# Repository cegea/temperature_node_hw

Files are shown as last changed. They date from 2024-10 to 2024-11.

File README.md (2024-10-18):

# Temperature node
PCB design for a temperature sensor based on SHT and ESP32.

#  Requirement Specifications

- Battery Operated: The node should operate on a battery with a lifespan of over a month.
- WiFi Connection: Supports 2.4 GHz WiFi to connect to a home network.
- MQTT Protocol: Publishes temperature and humidity data to an MQTT broker.
- Compact Design: Designed for easy placement in various locations around the home.
- Temperature and Humidity Reporting: Uses an SHT series sensor for accurate measurements.

# Functional Requirements Specification
## Electrical

- Battery Life: Should last more than a month on a single charge.
- Power Consumption: Optimized deep-sleep mode for low power consumption between readings.
- Input Voltage: 3.3V for ESP32 and 3V to 5V compatible for SHT sensors.
- Charging: Option for USB-C charging or solar panel for extended battery life.
- Voltage Regulation: Include a voltage regulator to ensure stable power delivery to ESP32 and the sensor.

## Mechanical

- Enclosure: IP65-rated enclosure for dust and water resistance if placed in areas prone to moisture.
- Size: Compact size, around 5cm x 5cm x 3cm, to fit easily on shelves or mounted on walls.
- Mounting (Optional): Option for wall mounting with screw holes or adhesive backing.
- Internal Antenna: PCB antenna for better WiFi range within the home.
- Access Ports: A small access port for USB charging and maintenance.

## Functional

- Data Reporting Interval: Configurable reporting interval (e.g., every 5 minutes, 10 minutes) to balance battery life and data frequency.
- Low Battery Alert: Sends an MQTT message when the battery level falls below a certain threshold.
- Temperature Range: Measures temperature from -20°C to +60°C.
- Humidity Range: Measures humidity from 0% to 100% relative humidity.
- OTA Updates: Supports Over-the-Air (OTA) firmware updates to improve functionality without physical access.
- Reconnection Logic: Automatically attempts to reconnect to WiFi and MQTT broker in case of network loss.
- Local Data Storage: Stores data temporarily in case of WiFi disconnection and uploads when the connection is restored.

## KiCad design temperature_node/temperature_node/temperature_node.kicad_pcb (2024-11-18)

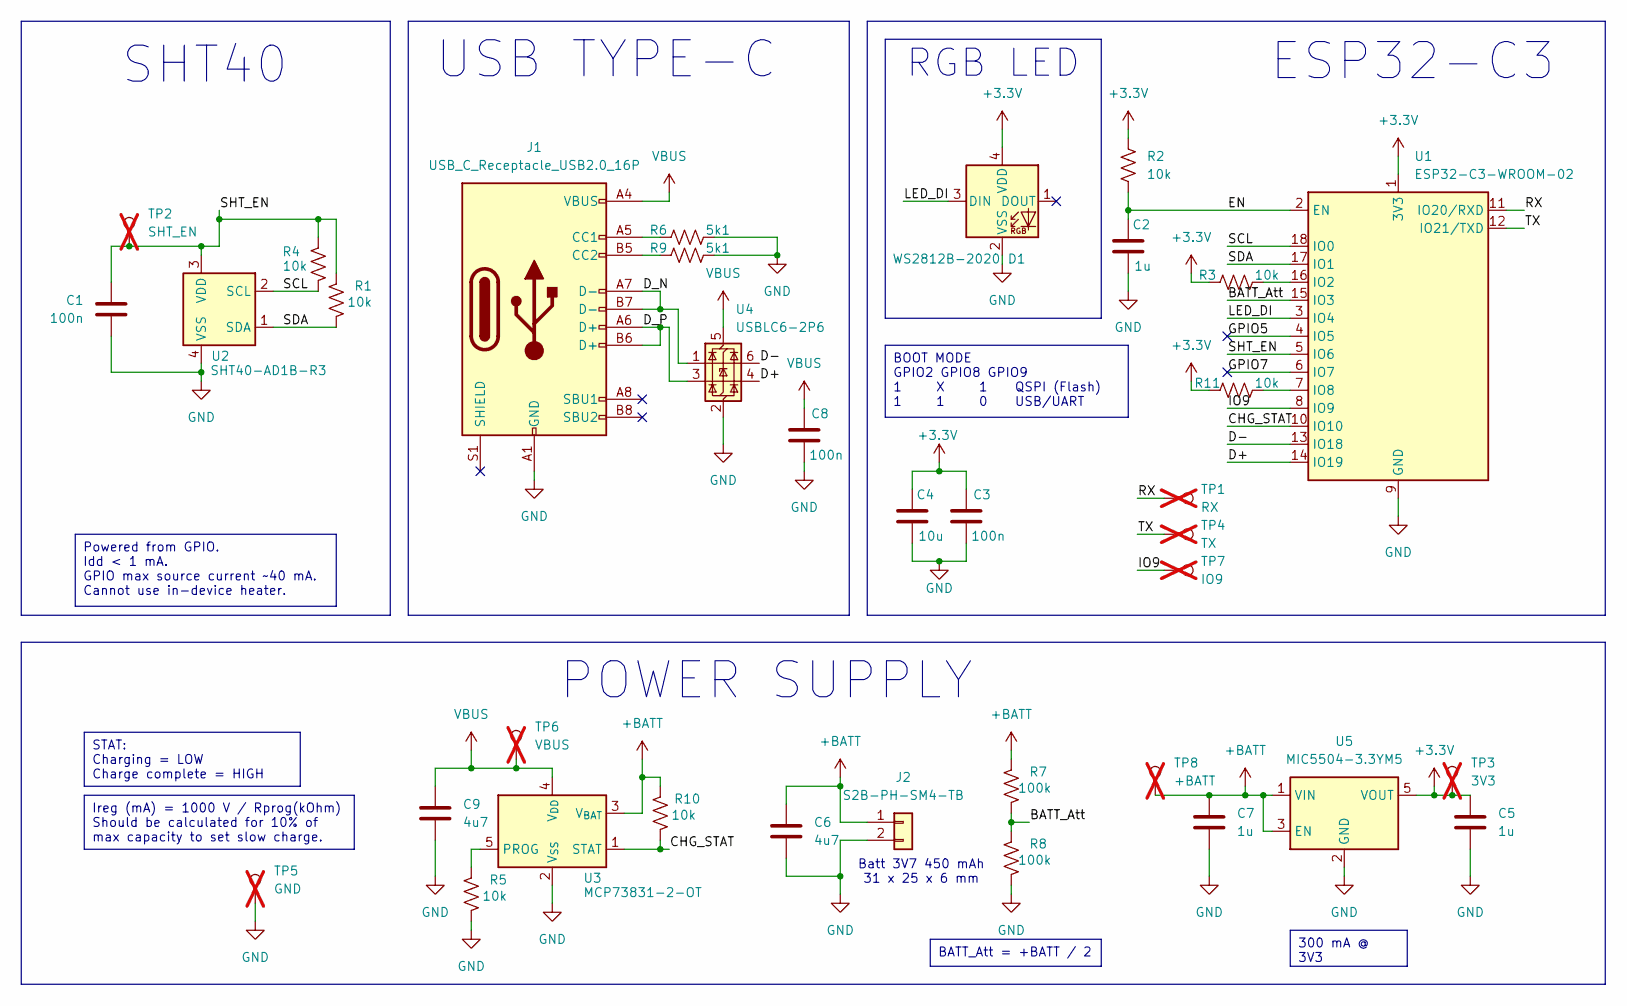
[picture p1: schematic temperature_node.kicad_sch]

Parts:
C1, C3, C8: 100n; C_0402_1005Metric; LCSC PN C60474
C2, C5, C7: 1u; C_0402_1005Metric; LCSC PN C60474
C4: 10u; C_0805_2012Metric; LCSC PN C17024
C6, C9: 4u7; C_0603_1608Metric; LCSC PN C913474
D1: WS2812B-2020; LED_WS2812B-2020_PLCC4_2.0x2.0mm; LCSC PN C965555
J1: USB_C_Receptacle_USB2.0_16P; USB_C_Receptacle_GCT_USB4110; LCSC PN C5143397
J2: S2B-PH-SM4-TB; JST_PH_S2B-PH-SM4-TB_1x02-1MP_P2.00mm_Horizontal; LCSC PN C295747
R1, R2, R3, R4, R5, R10, R11: 10k; R_0402_1005Metric; LCSC PN C723366
R6, R9: 5k1; R_0402_1005Metric; LCSC PN C25905
R7, R8: 100k; R_0402_1005Metric; LCSC PN C102760
TP1: RX; TestPoint_Pad_D1.0mm; not fitted
TP2: SHT_EN; TestPoint_Pad_D1.0mm; not fitted
TP3: 3V3; TestPoint_Pad_D1.0mm; not fitted
TP4: TX; TestPoint_Pad_D1.0mm; not fitted
TP5: GND; TestPoint_Pad_D1.0mm; not fitted
TP6: VBUS; TestPoint_Pad_D1.0mm; not fitted
TP7: IO9; TestPoint_Pad_D1.0mm; not fitted
TP8: +BATT; TestPoint_Pad_D1.0mm; not fitted
U1: ESP32-C3-WROOM-02; LCSC PN C2934560
U2: SHT40-AD1B-R3; Sensirion_DFN-4_1.5x1.5mm_P0.8mm_SHT4x_NoCentralPad
U3: MCP73831-2-OT; SOT-23-5; LCSC PN C150772
U4: USBLC6-2P6; SOT-666; LCSC PN C2827693
U5: MIC5504-3.3YM5; SOT-23-5; LCSC PN C3021093

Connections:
+3.3V: C3.1, C4.1, C5.1, D1.4 (VDD), R2.1, R3.2, R11.2, TP3.1, U1.1 (3V3), U5.5 (VOUT)
+BATT: C6.1, C7.1, J2.1, R7.1, R10.1, TP8.1, U3.3 (V_{BAT}), U5.1 (VIN), U5.3 (EN); also elsewhere on the board
/BATT_Att: R7.2, R8.1, U1.15 (IO3)
/CHG_STAT: R10.2, U1.10 (IO10), U3.1 (STAT)
/D+: U1.14 (IO19), U4.4 (I/O2)
/D-: U1.13 (IO18), U4.6 (I/O1)
/D_N: J1.A7 (D-), J1.B7 (D-), U4.1 (I/O1); also elsewhere on the board
/D_P: J1.A6 (D+), J1.B6 (D+), U4.3 (I/O2); also elsewhere on the board
/EN: C2.1, R2.2, U1.2 (EN)
/GPIO5: U1.4 (IO5)
/GPIO7: U1.6 (IO7)
/IO9: TP7.1, U1.8 (IO9)
/LED_DI: D1.3 (DIN), U1.3 (IO4)
/RX: TP1.1, U1.11 (IO20/RXD)
/SCL: R4.2, U1.18 (IO0), U2.2 (SCL)
/SDA: R1.2, U1.17 (IO1), U2.1 (SDA)
/SHT_EN: C1.1, R1.1, R4.1, TP2.1, U1.5 (IO6), U2.3 (VDD)
/TX: TP4.1, U1.12 (IO21/TXD)
GND: C1.2, C2.2, C3.2, C4.2, C5.2, C6.2, C7.2, C8.2, C9.2, D1.2 (VSS), J1.A1 (GND), J1.A12 (GND), J1.B1 (GND), J1.B12 (GND), J2.2, R5.2, R6.1, R8.2, R9.1, TP5.1, U1.9 (GND), U1.19 (GND), U2.4 (VSS), U3.2 (V_{SS}), U4.2 (GND), U5.2 (GND); also elsewhere on the board
unnamed 19: J1.A5 (CC1), R6.2; also elsewhere on the board
unnamed 20: J1.B5 (CC2), R9.2; also elsewhere on the board
unnamed: R3.1, U1.16 (IO2)
unnamed: R11.1, U1.7 (IO8)
unnamed: R5.1, U3.5 (PROG)
VBUS: C8.1, C9.1, J1.A4 (VBUS), J1.A9 (VBUS), J1.B4 (VBUS), J1.B9 (VBUS), TP6.1, U3.4 (V_{DD}), U4.5 (VBUS); also elsewhere on the board

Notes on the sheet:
Powered from GPIO. Idd < 1 mA. GPIO max source current ~40 mA. Cannot use in-device heater.
Ireg (mA) = 1000 V / Rprog(kOhm) Should be calculated for 10% of max capacity to set slow charge.
300 mA @ 3V3
BOOT MODE GPIO2 GPIO8 GPIO9 1 X 1 QSPI (Flash) 1 1 0 USB/UART
STAT: Charging = LOW Charge complete = HIGH
BATT_Att = +BATT / 2
SHT40
${TITLE}
POWER SUPPLY
Batt 3V7 450 mAh 31 x 25 x 6 mm
ESP32-C3
RGB LED
USB TYPE-C

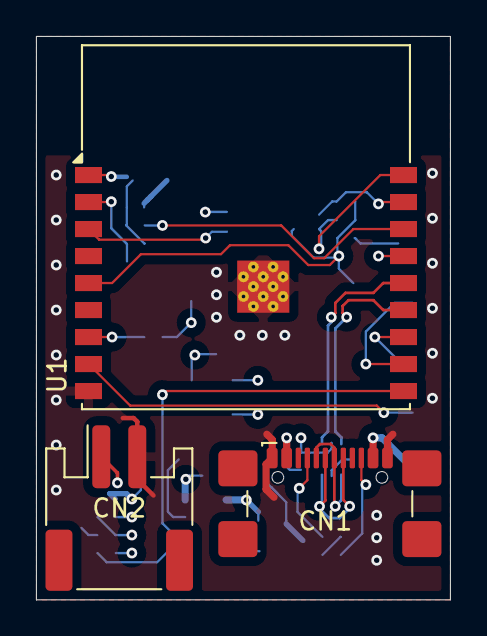
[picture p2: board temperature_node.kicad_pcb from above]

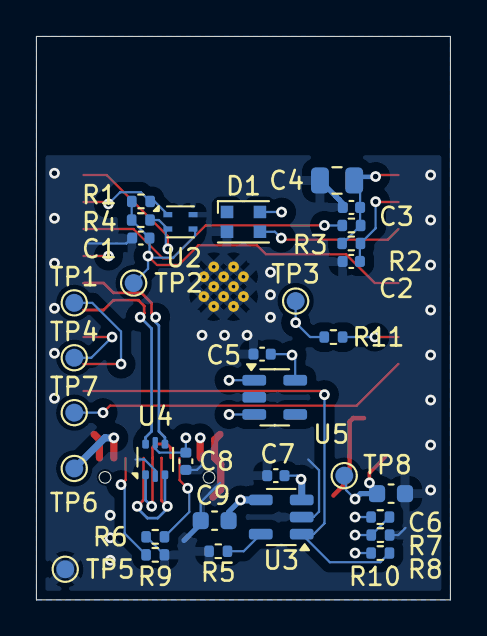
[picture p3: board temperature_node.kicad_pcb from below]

Board: 4 copper layers, 23.0 x 31.3 mm, 36 parts (33 on the bottom side), 23 nets.

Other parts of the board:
CN1: USB_C_Receptacle_USB2.0_16P; USB_C_Receptacle_GCT_USB4110
CN2: S2B-PH-SM4-TB; JST_PH_S2B-PH-SM4-TB_1x02-1MP_P2.00mm_Horizontal

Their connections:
+BATT: CN2.1; also elsewhere on the board
/D_N: CN1.A7 (D-), CN1.B7 (D-); also elsewhere on the board
/D_P: CN1.A6 (D+), CN1.B6 (D+); also elsewhere on the board
GND: CN1.A1 (GND), CN1.A12 (GND), CN1.B1 (GND), CN1.B12 (GND), CN2.2; also elsewhere on the board
unnamed 19: CN1.A5 (CC1); also elsewhere on the board
unnamed 20: CN1.B5 (CC2); also elsewhere on the board
VBUS: CN1.A4 (VBUS), CN1.A9 (VBUS), CN1.B4 (VBUS), CN1.B9 (VBUS); also elsewhere on the board

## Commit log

2024-10-18 Initial component selection and ESP32 peripherals
    [temperature_node.kicad_pcb, temperature_node.kicad_sch]
2024-10-19 Add esp32 module
    [temperature_node.kicad_sch]
2024-10-19 Connect USB and SHT40
    [temperature_node.kicad_sch]
2024-10-20 Finish pre stock review schematics
    [temperature_node.kicad_sch]
2024-10-30 Add notes to SCH and review pre PCB design
    [temperature_node.kicad_sch]
2024-10-30 Set slow charge to 100 mA with RPROG as 10k
    [temperature_node.kicad_sch]
2024-10-31 Use a smaller header for UART connector
    [temperature_node.kicad_sch]
2024-10-31 Initial PCB component placement
    [temperature_node.kicad_pcb]
2024-11-02 Add 1mm PAD test points
    [temperature_node.kicad_sch]
2024-11-02 Add GND test point and rearrange some nodes
    [temperature_node.kicad_sch]
2024-11-02 Preliminar placement
    [temperature_node.kicad_pcb]
2024-11-03 Import JLCPCB DRC
    [temperature_node.kicad_pcb]
2024-11-03 Re-placement to make the PCB smaller
    [temperature_node.kicad_pcb]
2024-11-04 Change battery connector to SMD
    [temperature_node.kicad_sch]
2024-11-04 Continue making the board smaller
    [temperature_node.kicad_pcb]
2024-11-04 Change USB C to SMD
    [temperature_node.kicad_sch]
2024-11-04 Add RX/TX nets
    [temperature_node.kicad_sch]
2024-11-04 Castellation pins for programming and resize for smaller board
    [temperature_node.kicad_pcb]
2024-11-04 Reposition connectors
    [temperature_node.kicad_pcb]
2024-11-05 Reposition some componentents and silkscreen
    [temperature_node.kicad_pcb]
2024-11-05 Replace 5x5 mm RGB Led for a 2x2 mm
    [temperature_node.kicad_sch]
2024-11-05 Replace TVS Diode with a smaller ESD + TVS protection for USB. Add datasheets
    [temperature_node.kicad_sch]
2024-11-05 Add decoupling capacitor at VBUS for ESD protection
    [temperature_node.kicad_sch]
2024-11-05 Placement pre routing
    [temperature_node.kicad_pcb]
2024-11-10 Add nets on both sides of the ESD proteciton
    [temperature_node.kicad_sch]
2024-11-10 Reorder connectors to shorter USB routing
    [temperature_node.kicad_pcb]
2024-11-10 Replace pad with side connector for programming enable
    [temperature_node.kicad_sch]
2024-11-10 PCB Routed pre DRC
    [temperature_node.kicad_pcb]
2024-11-11 Move board edge
    [temperature_node.kicad_pcb]
2024-11-14 Remove some DRC warnings
    [temperature_node.kicad_pcb]
2024-11-15 Constellation pads added property for DRC
    [temperature_node.kicad_pcb]
2024-11-15 Modify minimum hole size
2024-11-18 Replace header connector with testpoint
    [temperature_node.kicad_sch]
2024-11-18 Apply sch changes
    [temperature_node.kicad_pcb]
2024-11-18 Add note for battery and fix wrong reference for battery connector
    [temperature_node.kicad_sch]
2024-11-18 PCB DRC Ok
    [temperature_node.kicad_pcb]
2024-11-18 Reanotate PCB and SCH
    [temperature_node.kicad_pcb, temperature_node.kicad_sch]
2024-11-18 Add parameter for BOM and change some cap sizes for better availability
    [temperature_node.kicad_sch]
2024-11-18 update PCB with changed footprints
    [temperature_node.kicad_pcb]
2024-11-18 Mod F.silkscreen
    [temperature_node.kicad_pcb]
